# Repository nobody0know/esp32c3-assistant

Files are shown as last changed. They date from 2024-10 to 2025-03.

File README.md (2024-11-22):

# ESP32C3智能门禁助手

## 硬件开源:

[工程 - 立创开源硬件平台](https://oshwhub.com/nobody_0_knows/esp32c3-intelligent-access-contr)

## 开发环境：

使用VScode + ESP IDF V5.3.1/最新版本开发，参考立创实战派ESP32C3电路和部分代码

## 功能设计:

通过ST的陀螺仪：LSM6DSO的倾斜检测功能，将倾斜检测输出绑定到INT2脚，通过陀螺仪检测开关门的倾斜来实现唤醒ESP32C3并触发迎宾语音，目前按键按下boot按键即可触发音频

使用LVGL V8.3.10和NXP的guiguider设计界面，画了一个查看天气和时间的界面

使用[GPT-SoVITS-v2](https://www.modelscope.cn/studios/xzjosh/GPT-SoVITS-V2) 生成迎宾音频（项目中目前只生成了东雪莲的迎宾音频，需要其他可自行推理生成），写了一个用ffmpeg把mp3音频转pcm文件的脚本，然后软件文件夹中cmakelist中直接链接生成的pcm文件

## 物料成本:

墨水屏链接：[2.9寸墨水屏模块](https://item.taobao.com/item.htm?id=673989348784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)

项目成本大概120￥，墨水屏模块43.5+ESP32C3模块（不带IFA天线版）13.4+LSM6DSOWTR陀螺仪 6.06+CH343G 3.6 +板载麦克风（暂未开发可不贴）3.3+ES8311 2.9+PCA9557PW 2.64+钽电容1.9+TP5400 1.4 = 95.8￥加上各种杂七杂八的小件，FPC天线也才一块钱一根，合计一百来块不超一百五

## 焊接注意:

建议使用钢网加锡膏进行贴装焊接，淘宝买一个10cm*15cm的钢网，发给他Gerber文件即可，如果怕对位麻烦，边角四个安装孔钢网上也可以打孔

除了电池端子、屏幕模块的排母和开关外其他都可以一起贴装好后上热台

部分电容电阻可能会连锡搭在一起，问题不大，在热台上用镊子轻轻划开即可，小心别碰到其他元件

常连锡大户：TYPE C座子,ES8311,NS4150B,LSM6DSO这些估计得拿烙铁和松香划开，TYPE C我是每回必连的，都要自己划开

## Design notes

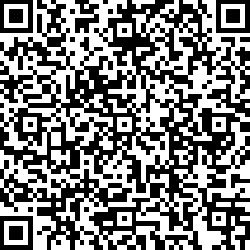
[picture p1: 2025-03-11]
doc/配网二维码.png

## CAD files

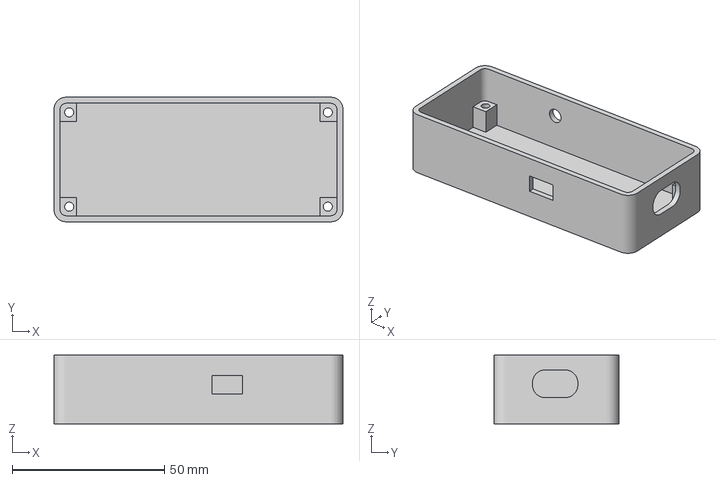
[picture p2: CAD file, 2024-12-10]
module/底壳.3mf
95.0 x 41.0 x 22.6 mm

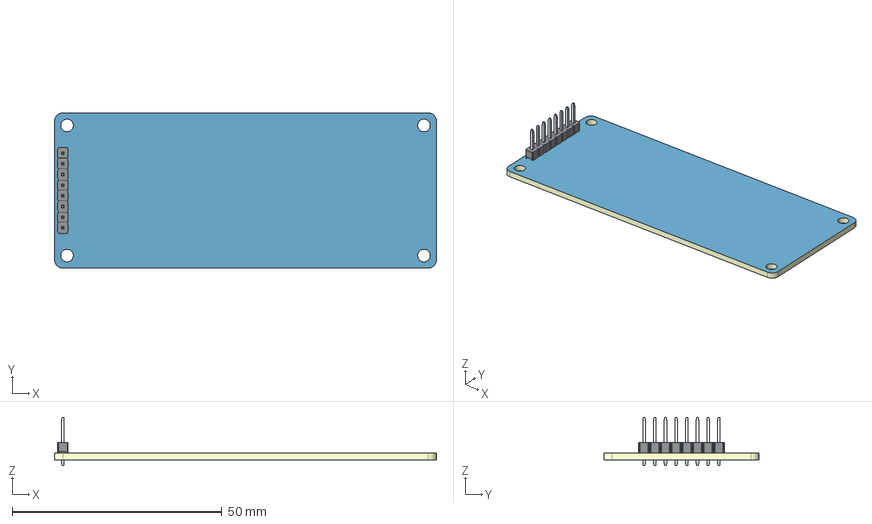
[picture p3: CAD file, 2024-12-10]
module/3D_screen_PCB_2024-12-06.step
91.0 x 37.0 x 11.5 mm
TopTrack
BottomTrack
Board

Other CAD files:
module/实体1.3mf
module/底壳3.3mf
module/底壳2.3mf

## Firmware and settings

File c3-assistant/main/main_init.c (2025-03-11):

#include "i2s_es8311.h"
#include "gpio_func.h"
#include "lsm6dso.h"
#include "esp_log.h"

#include "EPD.h"
#include "EPD_GUI.h"
#include "lvgl_hw.h"
#include "Pic.h"
#include "lvgl.h"
#include "lvgl_gui.h"
#include "esp32_wifi.h"
#include "esp32_wifi/get_ntptime.h"
#include "esp32_wifi/get_weather.h"
#include "pca9557/pca9557_driver.h"
#include "esp_pm.h"
#include "esp_sleep.h"
#include "common.h"
#include "sleep_wakeup.h"

static const char *TAG = "MAIN INIT";

uint8_t reset_flag = 0;
EventGroupHandle_t my_event_group;

void sleep_init()
{
    xEventGroupWaitBits(my_event_group, WIFI_MAIN_SCRE_OK_BIT, pdFALSE, pdFALSE, portMAX_DELAY);
    esp_sleep_enable_gpio_wakeup();
    esp_pm_config_t pm_config = {
        .max_freq_mhz = 80,
        .min_freq_mhz = 10,
        .light_sleep_enable = true};
    ESP_ERROR_CHECK(esp_pm_configure(&pm_config));
}

void app_main()
{
    if (gpio_init() != ESP_OK)
    {
        ESP_LOGE(TAG, "gpio init failed");
        abort();
    }
    else
    {
        ESP_LOGI(TAG, "gpio init success");
    }

    EPD_SPIInit();

    lvgl_gui_init();
    allgui_init();

    wifi_sta_init();

    ntp_time_init();
    weather_init();

    // pca9557_init();
    // lsm6dso_init();

    // es8311_user_init();

    sleep_init();
}

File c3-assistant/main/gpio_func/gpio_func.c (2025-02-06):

#include "sdkconfig.h"
#include "esp_system.h"
#include "esp_check.h"
#include "esp_err.h"
#include <stdio.h>
#include <string.h>
#include <stdlib.h>
#include <inttypes.h>
#include "freertos/FreeRTOS.h"
#include "freertos/task.h"
#include "freertos/queue.h"
#include "driver/gpio.h"
#include "driver/i2c.h"
#include "gpio_func.h"

static const char *TAG = "GPIO";

QueueHandle_t gpio_evt_queue = NULL;
bool usermsg_send_start;//debug to receive imu data

static void IRAM_ATTR gpio_isr_handler(void *arg)
{
    uint32_t gpio_num = (uint32_t)arg;
    xQueueSendFromISR(gpio_evt_queue, &gpio_num, NULL);
}

esp_err_t gpio_init()
{
    gpio_config_t io_conf = {
        .intr_type = GPIO_INTR_NEGEDGE, // disable interrupt
        .mode = GPIO_MODE_INPUT,       // set as output mode
        .pin_bit_mask = 1 << GPIO_NUM_2,        // bit mask of the pins
        .pull_down_en = 0,              // disable pull-down mode
        .pull_up_en = 1,                // enable pull-up mode
    };
    //configure GPIO with the given settings
    gpio_config(&io_conf);

    // 配置按键引脚
    io_conf.intr_type = GPIO_INTR_NEGEDGE;  // falling edge interrupt
    io_conf.mode = GPIO_MODE_INPUT;         // set as input mode
    io_conf.pin_bit_mask = 1 << GPIO_NUM_9; // bit mask of the pins GPIO9
    io_conf.pull_down_en = 0;               // disable pull-down mode
    io_conf.pull_up_en = 1;                 // enable pull-up mode
    gpio_config(&io_conf);                  // configure GPIO with the given settings

    //配置墨水屏spi引脚
    //CS
    io_conf.intr_type = GPIO_INTR_DISABLE;  
    io_conf.mode = GPIO_MODE_OUTPUT;         
    io_conf.pin_bit_mask = 1 << GPIO_NUM_4; // bit mask of the pins GPIO4
    io_conf.pull_down_en = 0;               
    io_conf.pull_up_en = 0;                 
    gpio_config(&io_conf);                  
    //DC   
    io_conf.pin_bit_mask = 1 << GPIO_NUM_6; // bit mask of the pins GPIO4             
    gpio_config(&io_conf);

    //bit mask of the pins that you want to set,e.g.GPIO18/19
    io_conf.pin_bit_mask = 1 << GPIO_NUM_7;
    //configure GPIO with the given settings
    gpio_config(&io_conf);//复位

    // create a queue to handle gpio event from isr
    gpio_evt_queue = xQueueCreate(1, sizeof(uint32_t));

    // install gpio isr service
    gpio_install_isr_service(0);
    // hook isr handler for specific gpio pin
    // gpio_isr_handler_add(GPIO_NUM_9, gpio_isr_handler, (void *)GPIO_NUM_9);
    gpio_isr_handler_add(GPIO_NUM_2, gpio_isr_handler, (void *)GPIO_NUM_2);

    /* Initialize I2C peripheral */
    const i2c_config_t es_i2c_cfg = {
        .sda_io_num = I2C_SDA_IO,
        .scl_io_num = I2C_SCL_IO,
        .mode = I2C_MODE_MASTER,
        .sda_pullup_en = GPIO_PULLUP_ENABLE,
        .scl_pullup_en = GPIO_PULLUP_ENABLE,
        .master.clk_speed = 100000,//iic速率是100k
    };
    ESP_RETURN_ON_ERROR(i2c_param_config(I2C_NUM, &es_i2c_cfg), TAG, "config i2c failed");
    ESP_RETURN_ON_ERROR(i2c_driver_install(I2C_NUM, I2C_MODE_MASTER, 0, 0, 0), TAG, "install i2c driver failed");
    return ESP_OK;
}

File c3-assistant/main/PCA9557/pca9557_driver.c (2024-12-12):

#include <stdio.h>
#include "driver/i2c.h"
#include "esp_log.h"
#include "freertos/FreeRTOS.h"
#include "freertos/task.h"
#include "esp_system.h"

#define I2C_MASTER_NUM 0             
#define PCA9557_ADDR                0x1C             // PCA9557 的 I²C 地址

// PCA9557寄存器地址
#define PCA9557_REG_INPUT           0x00   // 输入寄存器
#define PCA9557_REG_OUTPUT          0x01   // 输出寄存器
#define PCA9557_REG_POLARITY        0x02   // 极性反转寄存器
#define PCA9557_REG_CONFIG          0x03   // 配置寄存器

void pca9557_set_audio_high(void);

// 向PCA9557写数据
esp_err_t pca9557_write(uint8_t reg_addr, uint8_t data)
{
    esp_err_t err;
    uint8_t data_buf[2] = {reg_addr, data};
    
    err = i2c_master_write_to_device(I2C_MASTER_NUM, PCA9557_ADDR, data_buf, sizeof(data_buf), pdMS_TO_TICKS(100));
    if (err != ESP_OK) {
        ESP_LOGE("I2C", "Failed to write data to PCA9557");
    }
    else{
        ESP_LOGI("PCA9557","PCA9557 SET OK!");
    }
    return err;
}

// 初始化PCA9557配置，设置P1为输出
void pca9557_init(void)
{
    // 设置PCA9557的配置寄存器，使P1为输出
    pca9557_write(PCA9557_REG_CONFIG, 0xFD);  // 设置IO1为输出
    pca9557_write(PCA9557_REG_OUTPUT, 0x00);
}

// 设置P1输出高电平
void pca9557_set_audio_high(void)
{
    pca9557_write(PCA9557_REG_OUTPUT, 0x02);  // 输出0x02 设置P1为高电平
}

// 设置P1输出高电平
void pca9557_set_audio_low(void)
{
    pca9557_write(PCA9557_REG_OUTPUT, 0x00);  // 输出0x02 设置P1为高电平
}

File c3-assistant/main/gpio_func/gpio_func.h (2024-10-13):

#include "esp_err.h"
/* I2C port and GPIOs */
#define I2C_NUM         (0)
#if CONFIG_IDF_TARGET_ESP32 || CONFIG_IDF_TARGET_ESP32S2 || CONFIG_IDF_TARGET_ESP32S3
#define I2C_SCL_IO      (GPIO_NUM_16)
#define I2C_SDA_IO      (GPIO_NUM_17)
#elif CONFIG_IDF_TARGET_ESP32H2
#define I2C_SCL_IO      (GPIO_NUM_8)
#define I2C_SDA_IO      (GPIO_NUM_9)
#elif CONFIG_IDF_TARGET_ESP32P4
#define I2C_SCL_IO      (GPIO_NUM_8)
#define I2C_SDA_IO      (GPIO_NUM_7)
#else
#define I2C_SCL_IO      (GPIO_NUM_1)
#define I2C_SDA_IO      (GPIO_NUM_0)
#endif

extern esp_err_t gpio_init();

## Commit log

2024-10-13 init 移植es8311实现按键发声
    莲宝的声音听起来还是顺耳一些
2024-10-13 添加陀螺仪和wifi和udp数据采集功能
    [partitions.csv, 开关门角速度数据.xlsx]
2024-10-20 成功驱动墨水屏
2024-10-23 修复 lvgl跑起来后 栈溢出问题，系未调用lv init
    [main_init.c]
2024-10-24 更改为三线SPI模式
2024-10-24 add gui guider and 3 wire spi ok
2024-10-26 网络读取天气和ntp授时和LVGL初步显示天气
    [partitions.csv]
2024-10-28 GUI基本完成，天气UI初步压测正常，待长时压测
    [开关门角速度数据.xlsx]
2024-11-20 add imu code
2024-11-20 修复陀螺仪读取问题，优化代码逻辑
2024-11-20 修复偶发启动屏幕失效的问题
2024-11-21 优化wifi连接逻辑，添加配网逻辑以及重连失败过多后重新配网的机制
2024-12-02 添加IMU开门检测
    门有强震动还是会触发，但是已经滤除部分震动的低频噪声，只保留开关门时的高频数据，基本上能做到只当进入室内的开关门，开门悬停时会触发，只有间隔一段时间触发两次开关门动作（包括开门悬停动作）才会播放迎宾音频，表征单人间内住户进门（默认出门状态）
2024-12-02 添加低功耗，autolightsleep 保持wifi连接的策略，平均功耗50mW
2024-12-05 低功耗压到2ma
2024-12-05 解决进入auto lightsleep后屏幕不刷新的问题
2024-12-10 修复震动导致触发的问题
    [3D_screen_PCB_2024-12-06.step, 实体1.3mf, 底壳.3mf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]
2024-12-10 第五版硬件调试
2024-12-12 完成低功耗部分，全功能完成
2025-02-06 添加晚上不迎宾的功能
2025-03-11 切换区域为南山
